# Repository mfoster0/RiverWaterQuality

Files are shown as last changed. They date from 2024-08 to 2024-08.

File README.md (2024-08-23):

# ♒Detecting River Water Quality 

<p align='center'>
  Final deployment in the River Lea
</p>
<br/>

## Contents
- [Overview](#overview) 
- [Features](#features) 
- [Hardware Components](#hardware-components) 
- [Set-up](#set-up) 
- [Usage](#usage)
- [Thanks](#Thanks) 
- [License](#license) 
- [Contact](#contact)

## Overview
<p align='center'>
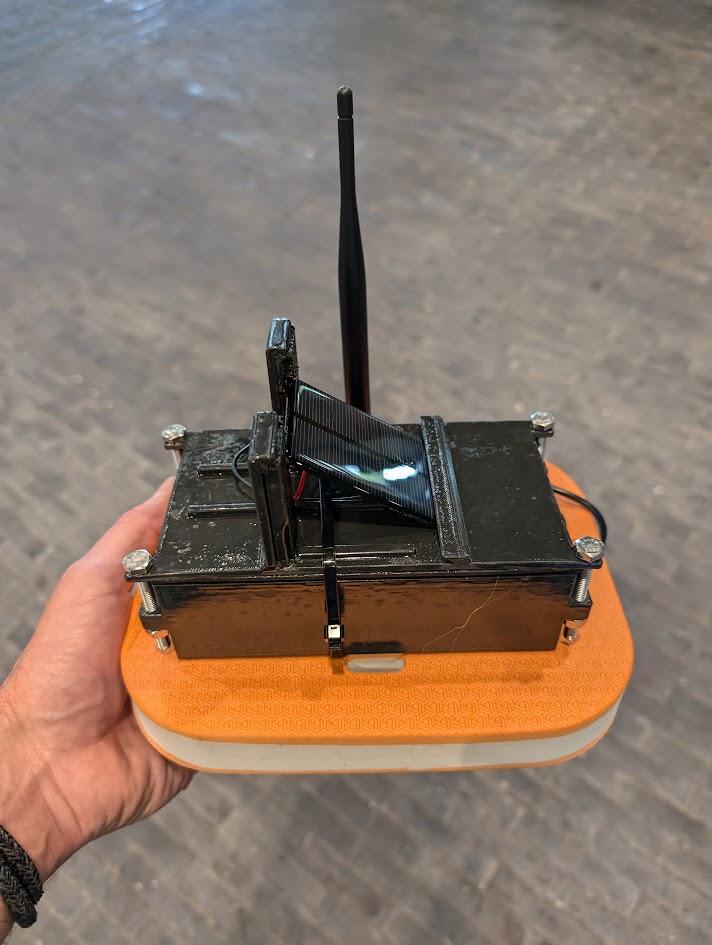
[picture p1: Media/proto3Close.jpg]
Prototype #3 before deployment
  
 </p>
This project created an IoT device that monitors river water quality in real-time. It detects temperature, electrical conductivity (EC) and the colour properties of water. It is an in-situ autonomous device that harvests solar energy and stores it in recycled vape batteries. The MCU is an Arduino MKR 1310 which sends the data over LoRa. The aim is to allow a user to remotely understand the changing water conditions to identify potential pollution events.
This project formed part of UCL Connected Environments MSc which concluded with an exhibition. This git also includes the exhibit details.
<br/>

<p align='center'>
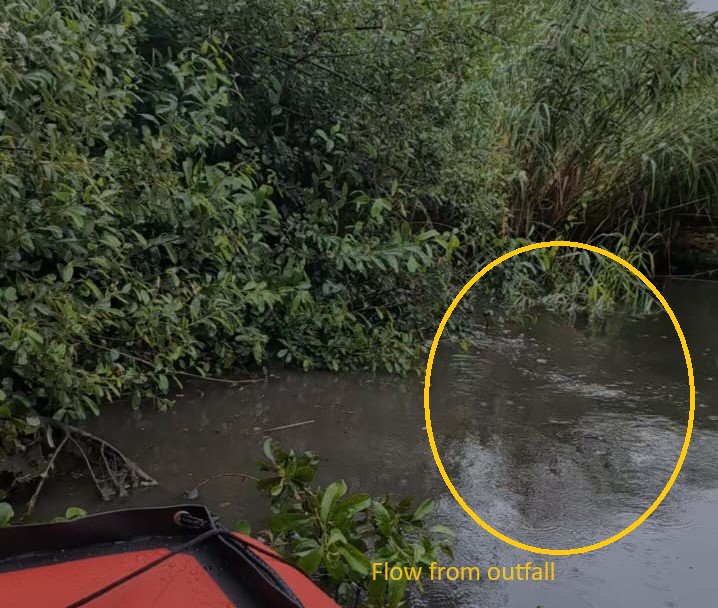
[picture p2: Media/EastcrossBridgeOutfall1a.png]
Location of deployment
  
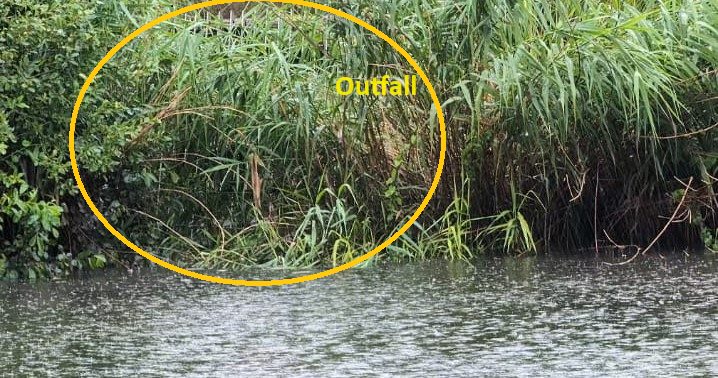
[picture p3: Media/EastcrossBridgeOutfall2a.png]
Deployment site
  
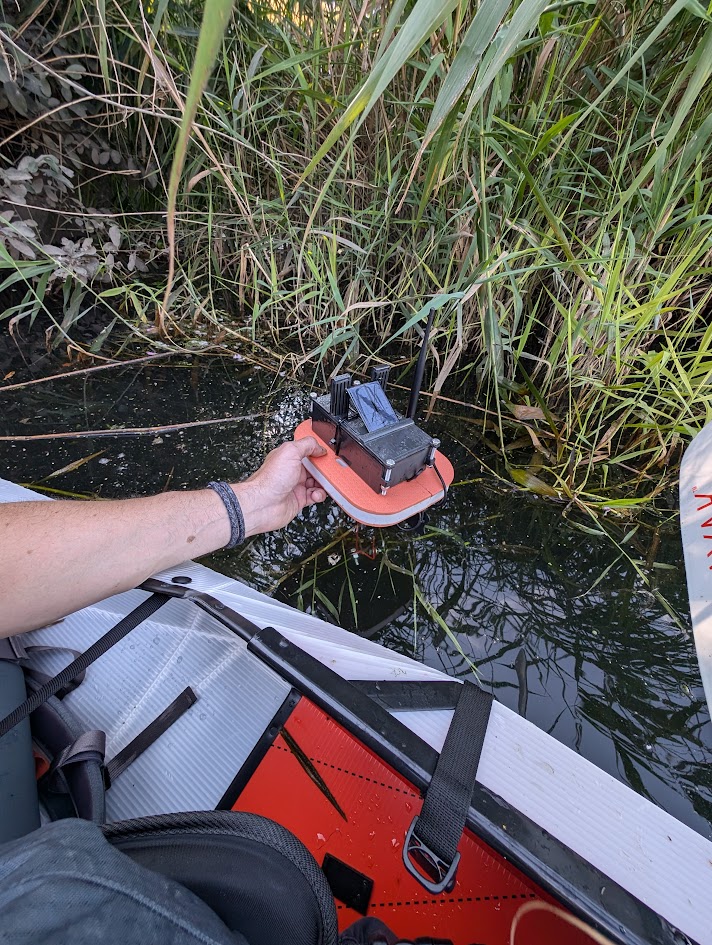
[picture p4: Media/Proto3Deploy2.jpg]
Prototype #3 being deployed
  
 
 </p>
 
## Features
- A custom 4-pole, graphite EC sensor
- Use of a TCS34725 with in external LED through optical fibre
- A DS18B20 temperature sensor
- LoRaWAN data transfer using Arduino MKR 1310
- Powered by a solar cell and upcycled vape batteries!

## Hardware Components 
- **Temperature Sensor** DS18B20
- **TCS34725 Colour Sensor**: [Learn more](https://www.waveshare.com/wiki/TCS34725_Color_Sensor) 
- **Custom Electrical Conductivity Sensor** inspired by the excellent Cave Pearl Project (https://thecavepearlproject.org/2017/08/12/measuring-electrical-conductivity-with-an-arduino-part1-overview/)
- **Arduino MKR1310 MCU** 
- **Solar Panel and Recycled Vape Batteries**

## Set-up
### Enclosure
The enclosure for this device was 3D printed with PLA and coated in an eco-friendly epoxy to waterproof it (tip: mixed results with this approach so thoroughly test how waterproof your final enclosure is). The files are in the *FusionFiles* directory. The float designs are included BUT the prototype deployed using these sank. The last version was deployed using a child’s kickboard as its float, which worked very well.

<p align='center'>
 The issues causes by not being waterproof can be seen below!

</p>
<p align='center'>
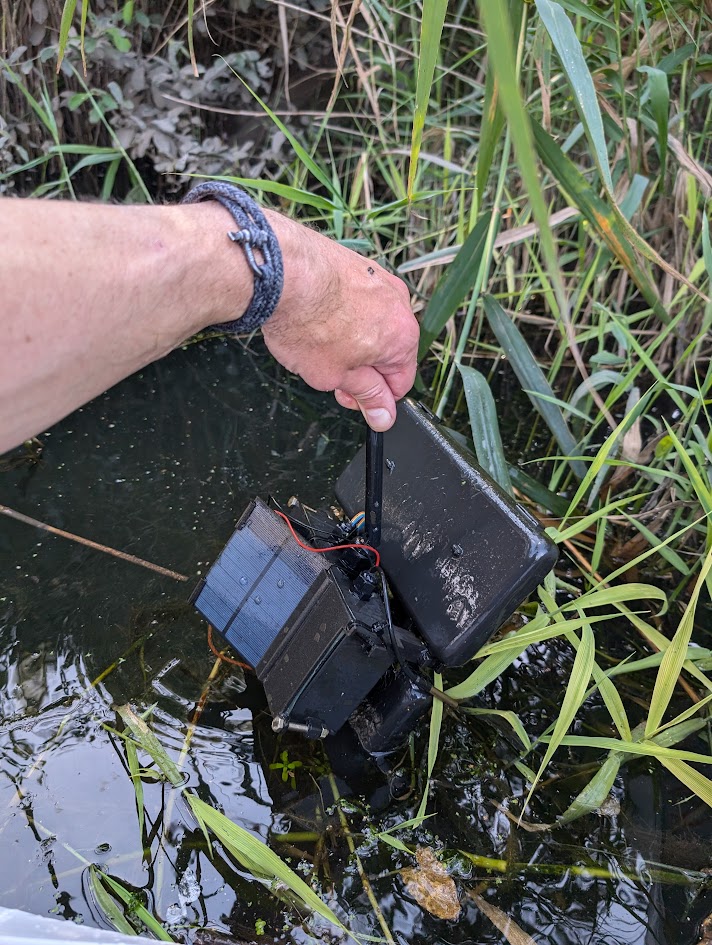
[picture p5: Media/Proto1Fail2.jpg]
A sunken prototype #1 being retrived
  
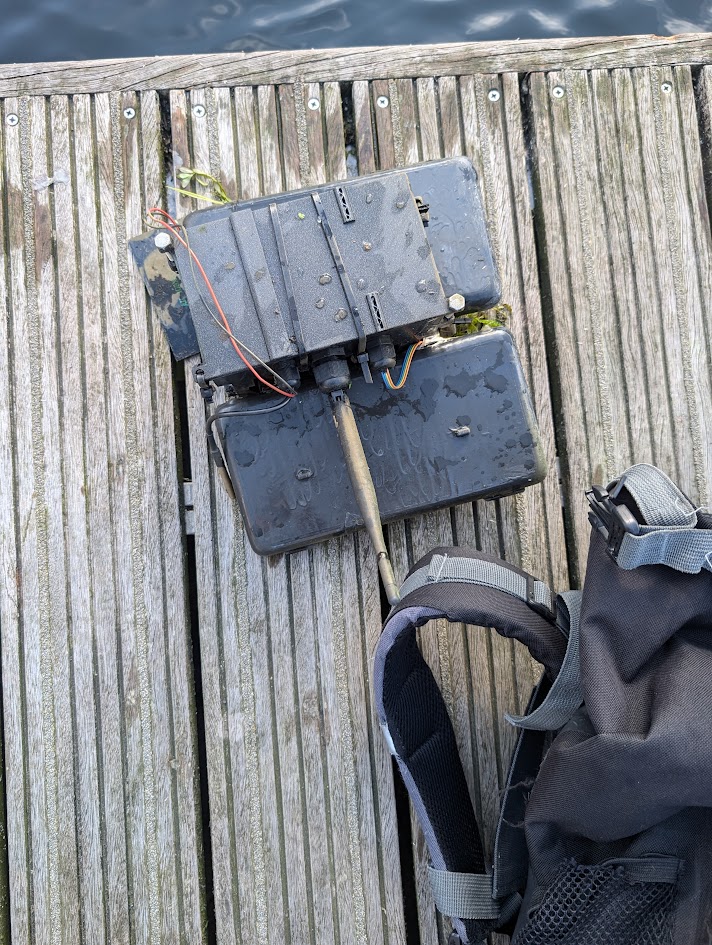
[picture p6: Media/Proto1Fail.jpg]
Prototype #1 after retrieval
  
 </p>
 
### Sensors
#### Electrical Conductivity (EC)
The EC sensor uses a 4-pole design to reduce electrolysis and increase the accuracy of the sensor. Graphite was used for electrodes for its high conductivity and resistance to electrolysis. The prototypes used 2mm 8B graphite to maximise the conductivity of the graphite but, due to its softness, this is difficult to work with. A conductive glue was used to attach the electrode to the wire.
The current oscillates from the two outer poles, with the two inner poles measuring the voltage. A third voltage measurement is taken across one of the resistors connected to the outer poles. 
<p align='center'>
 Below are images of the electrode holder 3D model and the graphite electrodes attached using conductive glue.
</p>
<p align='center'>
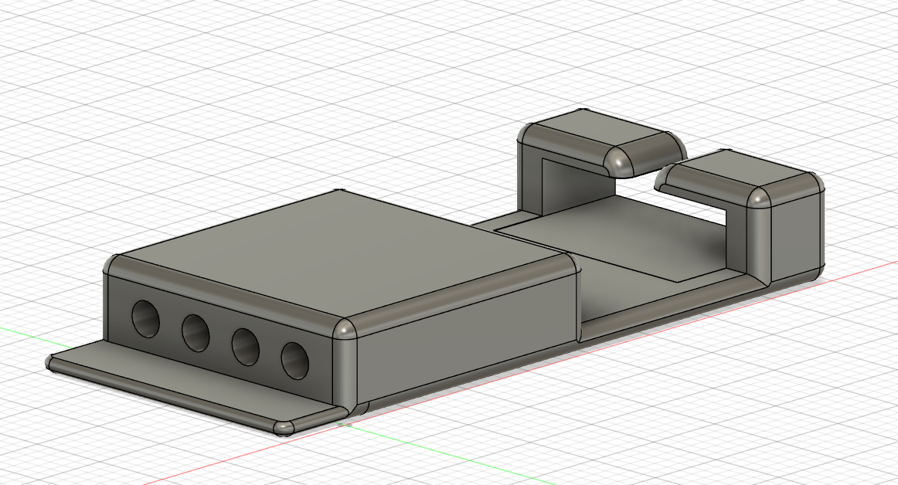
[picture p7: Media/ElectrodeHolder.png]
3D model of the electrode holder
   
 
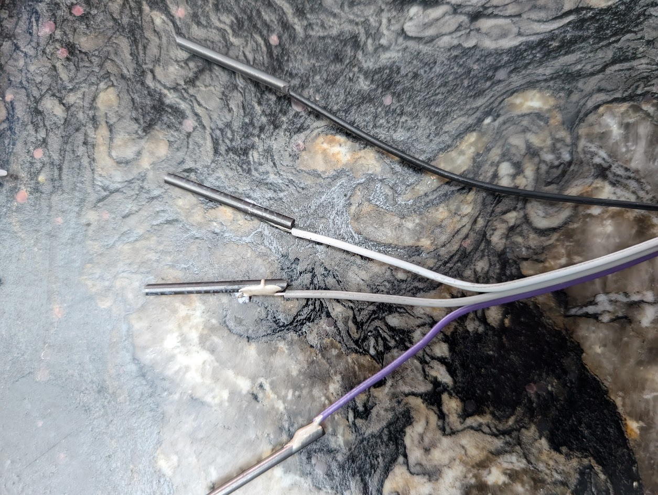
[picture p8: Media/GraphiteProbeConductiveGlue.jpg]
Photo of the 4 wires attached to the graphite electrodes with conductive glue
   
 </p>

#### TCS34725
To detect the colour of the water, light was emitted from a white LED, transmitted through the water and detected by the TCS34725. The sensor is keep away from the water by using optical fibre to transfer the light into and out of the water. An early version made use of the sensor’s onboard LED using backscattered light for colour detection but the results were poor which led to the latest design where light source is directed at the sensor.
<p align='center'>
 Below are the TCS34725 sensor and 3D print of optical fibre frame with its water chamber visible in the center
</p>
<p align='center'>
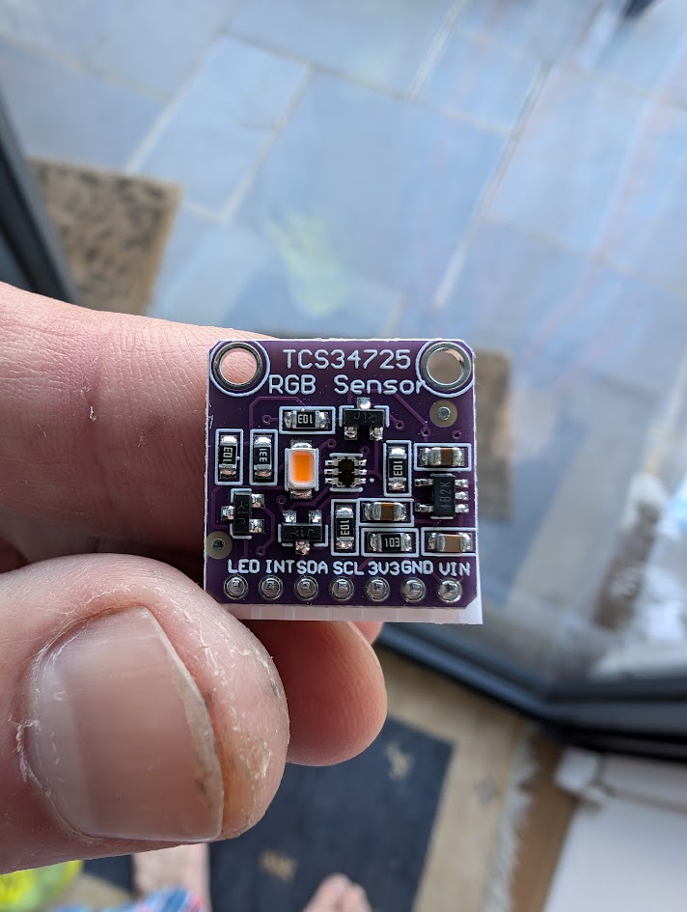
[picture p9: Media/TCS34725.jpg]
Photo of the TCS34725
   
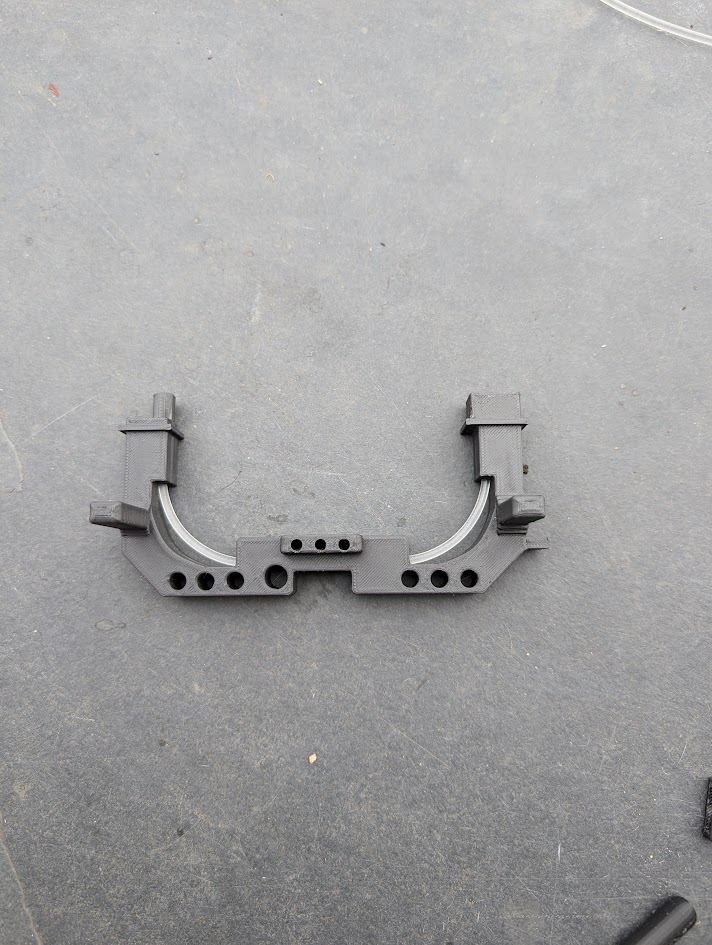
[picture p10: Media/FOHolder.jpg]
Photo of the Optical Fibre holder
   
 </p>

#### DS18B20
The temperature sensor had no modifications and has the standard 4.7k ohm resistor setup. https://www.researchgate.net/figure/Design-of-Ds1820-Temperature-Sensor_fig3_260944398
#### Circuit
Below are the circuit diagrams. Through testing 510 ohm resistors were found to give the most sensitive results for pure water to sea water salinity levels.

A custom PCB was used for the final build. Files are in the *FusionFiles/PCB* folder. The resistor component had a short in the protoype. That is corrected in these files. The schematic is correct but make sure to double check the PCB if this to be used.

<p align='center'>
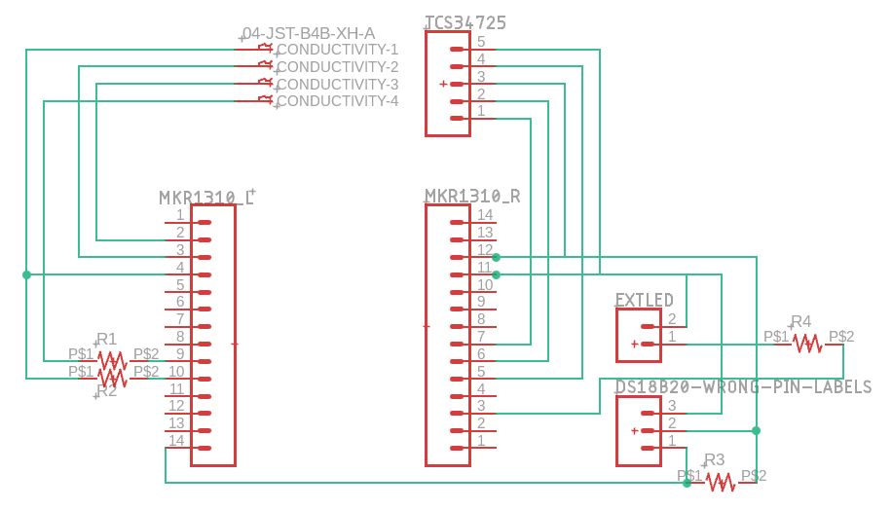
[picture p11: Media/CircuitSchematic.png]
Schematic for the circuit
  
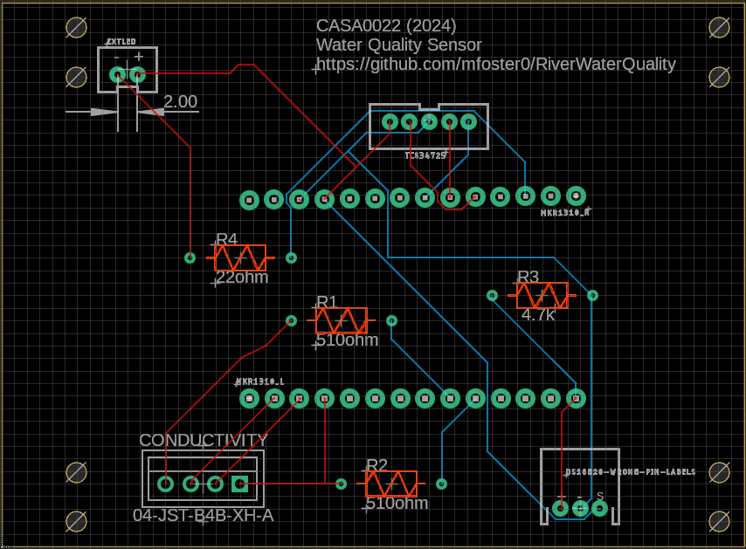
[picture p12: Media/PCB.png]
PCB Design
  
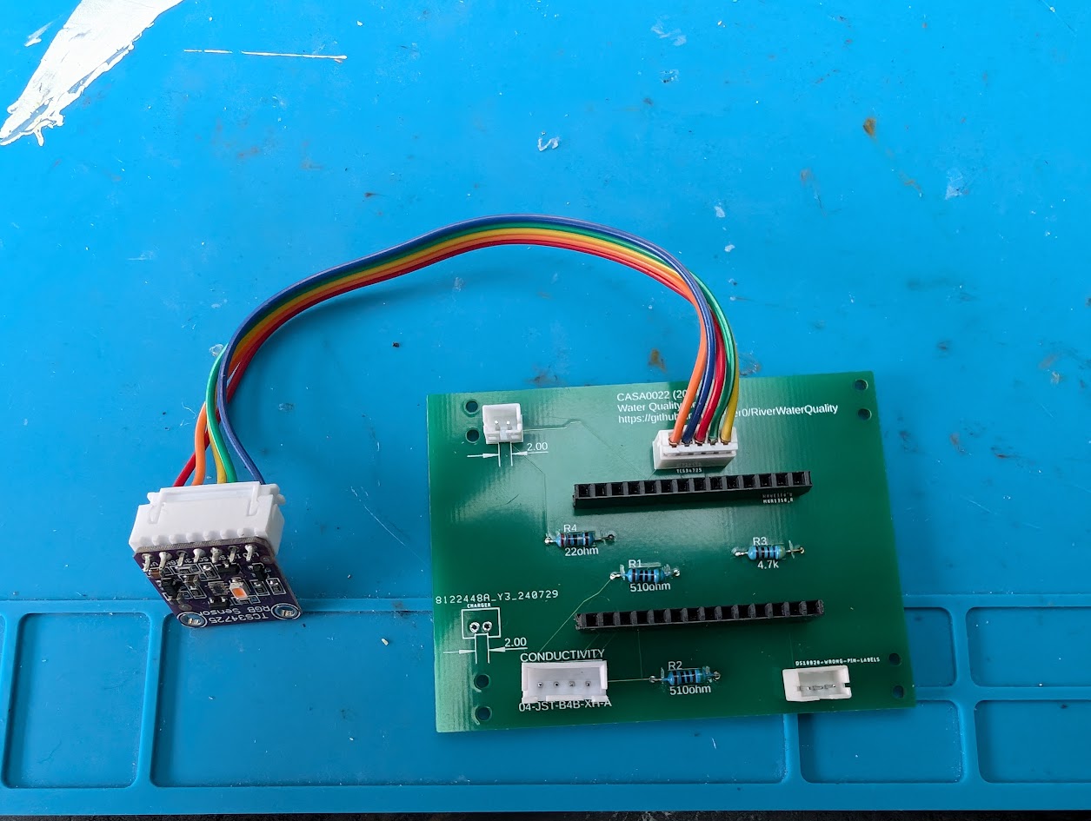
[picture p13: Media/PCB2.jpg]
Image of the actual PCB
  
 </p>

### Code
*Prod_RiverWaterQuality* holds the Arduino code for the final version. Multiple boards and sensors were tested before arriving at this version. Some of the code for those is stored in the *InitalScripts* directory.  

The read of the voltages values are taken in the loop with the pin outputs alternating between HIGH and LOW to get the oscillating current.
```c++
//function to get conductivity values
//to the code takes multiple readings
//the highest and lowest values are dropped to help reduce the opportunity for erroneous values to be included
//the central values are then averaged 
void processConductivity(){
  // Generate oscillating current and read voltages
  std::vector<int> readings1;
  std::vector<int> readings2;
  std::vector<int> resistorReadings;
  
  unsigned long startTime = millis();
  int sampleCount = 0;

  //loop for specified time taking multiple readings
  while (millis() - startTime < SAMPLE_DELAY) {
    digitalWrite(OUTER_ELECTRODE1, HIGH);
    digitalWrite(OUTER_ELECTRODE2, LOW);
    delayMicroseconds(500000 / OSCILLATION_FREQUENCY);
    
    readings1.push_back(analogRead(INNER_ELECTRODE1));
    readings2.push_back(analogRead(INNER_ELECTRODE2));
    resistorReadings.push_back(analogRead(RESISTOR_READ));
    sampleCount++;
    
    digitalWrite(OUTER_ELECTRODE1, LOW);
    digitalWrite(OUTER_ELECTRODE2, HIGH);
    delayMicroseconds(500000 / OSCILLATION_FREQUENCY);
    
    readings1.push_back(analogRead(INNER_ELECTRODE1));
    readings2.push_back(analogRead(INNER_ELECTRODE2));
    resistorReadings.push_back(analogRead(RESISTOR_READ));
    sampleCount++;
  }
  
  //process the arrays, dropping highest and lowest values before averaging
  float avgVoltage1 = trimAndAverageReadings(readings1, sampleCount);
  float avgVoltage2 = trimAndAverageReadings(readings2, sampleCount);
  float avgResistorVoltage = trimAndAverageReadings(resistorReadings, sampleCount);
  
  //read temperature
  sensors.requestTemperatures(); // get temperature
  float temperature = sensors.getTempCByIndex(0); // Get temperature in Celsius
  Temperature = (uint16_t)(temperature * 100.0);
  Serial.print("temperature: ");
  Serial.println(temperature,3);
  Serial.println(Temperature);

  //convert to voltages
  float voltage1 = (avgVoltage1 / UPPER_BOUND) * BOARD_VOLTAGE;
  float voltage2 = (avgVoltage2 / UPPER_BOUND) * BOARD_VOLTAGE;
  float resistorVoltage = (avgResistorVoltage / UPPER_BOUND) * BOARD_VOLTAGE;

  // Calc voltage drop in solution
  float solutionVoltage = voltage2 - voltage1;

  // Calc resistance of solution
  float resistance = resistorVoltage / (solutionVoltage / RESISTOR_VALUE); 

  // Calc raw conductivity - any temperature compensation to be done off device
  float rawConductivity = 1.0 / resistance; 

  Conductivity = (uint16_t)(rawConductivity * 100);
  Serial.println(Conductivity);

```
The reads do get anomalies. To counter this many reads are taken with just the central values being used and the highest and lowest values dropped.  
```c++
//drop highest and lowest n% of values to reduce noise
float trimAndAverageReadings(std::vector<int>& readings, int numReadings) {
    if (readings.empty() || numReadings < 3) {
        return 0.0f;  // return 0 if the list is empty or numReadings is too small
    }

    //sort the vector
    std::sort(readings.begin(), readings.end());

    // calc number of elements to trim
    int trimCount = std::round(numReadings * 0.2);  // 20% from top and bottom
    
    // don't trim more than half the values
    trimCount = std::min(trimCount, ((int)readings.size() / 2) - 1);

    // sum up
    float sum = 0;
    for (int i = trimCount; i < readings.size() - trimCount; ++i) {
        sum += readings[i];
    }

    // retrun average
    int remainingElements = readings.size() - (2 * trimCount); //2x - 1 at each end
    return sum / remainingElements;
}
```
The device sleeps for 10 minutes between reads (*LowPower.deepSleep(600000);*). This ensures that it conserves power and stays well within The Things Network fair use conditions. When the device wakes it reads the current sensor values and sends them using LoRa.
```c++
//from setup
…
  //startup LoRa modem instance set regional band 
  if (!modem.begin(EU868)) {
    Serial.println("Failed to start module");
  }

  Serial.print("Your device EUI is: ");
  Serial.println(modem.deviceEUI());

  int connected = modem.joinOTAA(appEui, appKey);
  if (!connected) {
    Serial.println("Unable to connect");
  }
…

//send data over LoRaWAN
void sendLora(){
    // Split readings (16 bits) into 2 bytes of 8
  int payloadLen = 10;
  Serial.println(payloadLen);
  
  byte payload[payloadLen];
  payload[0] = highByte(Temperature);
  payload[1] = lowByte(Temperature);
  payload[2] = highByte(Conductivity);
  payload[3] = lowByte(Conductivity);
  
  payload[4] = highByte(Red);
  payload[5] = lowByte(Red);
  payload[6] = highByte(Green);
  payload[7] = lowByte(Green);
  payload[8] = highByte(Blue);
  payload[9] = lowByte(Blue);

  modem.beginPacket();
  modem.write(payload, sizeof(payload));
  int err = modem.endPacket(true);
  if (err > 0) {
    Serial.println("Message sent correctly");
  } else {
    Serial.println("Error sending message");
  }
}

```

## Thanks
 - Dr Izzy Bishop (UCL) for input and help deploying the devices
 - Lewis Elmes (Environment Agency) for approving the deployments

## License
MIT License

Copyright (c) 2024 mfoster0

Permission is hereby granted, free of charge, to any person obtaining a copy
of this software and associated documentation files (the "Software"), to deal
in the Software without restriction, including without limitation the rights
to use, copy, modify, merge, publish, distribute, sublicense, and/or sell
copies of the Software, and to permit persons to whom the Software is
furnished to do so, subject to the following conditions:

The above copyright notice and this permission notice shall be included in all
copies or substantial portions of the Software.

THE SOFTWARE IS PROVIDED "AS IS", WITHOUT WARRANTY OF ANY KIND, EXPRESS OR
IMPLIED, INCLUDING BUT NOT LIMITED TO THE WARRANTIES OF MERCHANTABILITY,
FITNESS FOR A PARTICULAR PURPOSE AND NONINFRINGEMENT. IN NO EVENT SHALL THE
AUTHORS OR COPYRIGHT HOLDERS BE LIABLE FOR ANY CLAIM, DAMAGES OR OTHER
LIABILITY, WHETHER IN AN ACTION OF CONTRACT, TORT OR OTHERWISE, ARISING FROM,
OUT OF OR IN CONNECTION WITH THE SOFTWARE OR THE USE OR OTHER DEALINGS IN THE
SOFTWARE.

## Contact
Please let me know if you find errors in here or if you taking the project further.
ucfnamm@ucl.ac.uk

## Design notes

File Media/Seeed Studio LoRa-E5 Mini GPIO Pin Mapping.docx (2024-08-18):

Seeed Studio LoRa-E5 Mini GPIO Pin Mapping

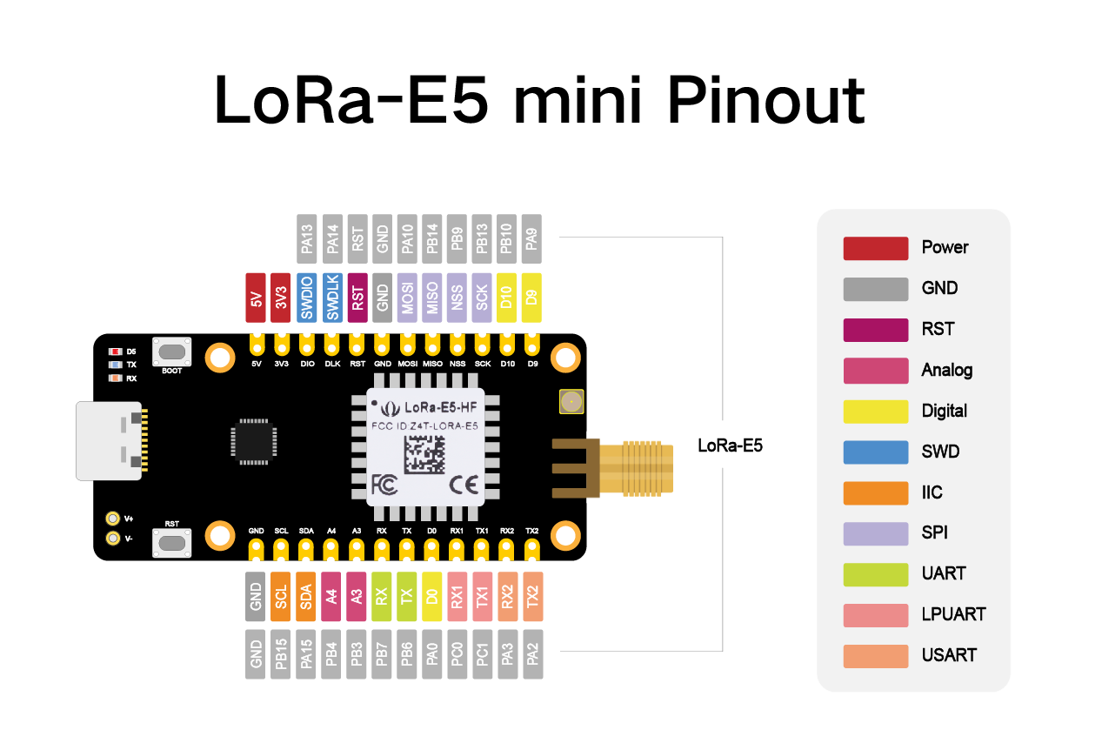
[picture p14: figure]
pir

Pin | Pin # | HAL GPIO Pin | | Pin | Pin # | HAL GPIO Pin | | Pin | Pin # | HAL GPIO Pin
PA0 | 18 | GPIO_PIN_0 | | PB1 | 33 | GPIO_PIN_1 | | PC2 | 43 | GPIO_PIN_2
PA1 | 19 | GPIO_PIN_1 | | PB2 | 34 | GPIO_PIN_2 | | PC3 | 44 | GPIO_PIN_3
PA2 | 20 | GPIO_PIN_2 | | PB3 | 3 | GPIO_PIN_3 | | PC4 | 45 | GPIO_PIN_4
PA3 | 21 | GPIO_PIN_3 | | PB4 | 4 | GPIO_PIN_4 | | PC5 | 46 | GPIO_PIN_5
PA4 | 22 | GPIO_PIN_4 | | PB5 | 5 | GPIO_PIN_5 | | PC6 | 47 | GPIO_PIN_6
PA5 | 23 | GPIO_PIN_5 | | PB6 | 6 | GPIO_PIN_6 | | PC7 | 48 | GPIO_PIN_7
PA6 | 24 | GPIO_PIN_6 | | PB7 | 7 | GPIO_PIN_7 | | PC8 | 49 | GPIO_PIN_8
PA7 | 25 | GPIO_PIN_7 | | PB8 | 8 | GPIO_PIN_8 | | PC9 | 50 | GPIO_PIN_9
PA8 | 26 | GPIO_PIN_8 | | PB9 | 9 | GPIO_PIN_9 | | PC10 | 51 | GPIO_PIN_10
PA9 | 11 | GPIO_PIN_9 | | PB10 | 35 | GPIO_PIN_10 | | PC11 | 52 | GPIO_PIN_11
PA10 | 12 | GPIO_PIN_10 | | PB11 | 36 | GPIO_PIN_11 | | PC12 | 53 | GPIO_PIN_12
PA11 | 13 | GPIO_PIN_11 | | PB12 | 37 | GPIO_PIN_12 | | PC13 | 2 | GPIO_PIN_13
PA12 | 14 | GPIO_PIN_12 | | PB13 | 38 | GPIO_PIN_13 | | PC14 | 16 | GPIO_PIN_14
PA13 | 29 | GPIO_PIN_13 | | PB14 | 39 | GPIO_PIN_14 | | PC15 | 17 | GPIO_PIN_15
PA14 | 30 | GPIO_PIN_14 | | PB15 | 40 | GPIO_PIN_15 | | PD0 | 54 | GPIO_PIN_0
PA15 | 31 | GPIO_PIN_15 | | PC0 | 41 | GPIO_PIN_0 | | PD1 | 55 | GPIO_PIN_1
PB0 | 32 | GPIO_PIN_0 | | PC1 | 42 | GPIO_PIN_1

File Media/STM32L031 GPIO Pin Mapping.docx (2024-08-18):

# STM32L031 GPIO Pin Mapping

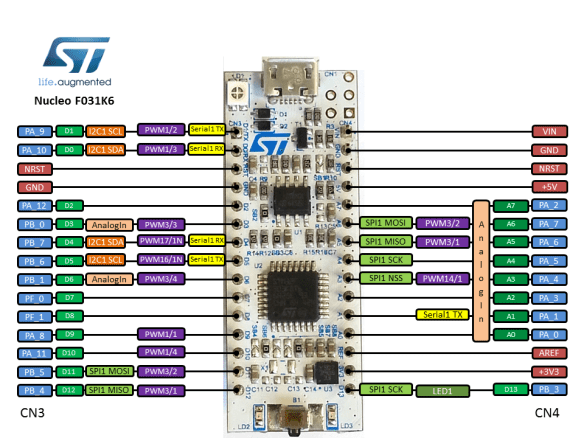
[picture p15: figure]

Pin | Pin # | HAL GPIO Pin Definition | | Pin | Pin # | HAL GPIO Pin Definition | | Pin | Pin # | HAL GPIO Pin Definition
PA0 | 1 | GPIO_PIN_0 | | PA12 | 19 | GPIO_PIN_12 | | PB8 | 32 | GPIO_PIN_8
PA1 | 2 | GPIO_PIN_1 | | PA13 | 21 | GPIO_PIN_13 | | PB9 | 33 | GPIO_PIN_9
PA2 | 3 | GPIO_PIN_2 | | PA14 | 22 | GPIO_PIN_14 | | PB10 | 34 | GPIO_PIN_10
PA3 | 4 | GPIO_PIN_3 | | PA15 | 23 | GPIO_PIN_15 | | PB11 | 35 | GPIO_PIN_11
PA4 | 5 | GPIO_PIN_4 | | PB0 | 24 | GPIO_PIN_0 | | PB12 | 36 | GPIO_PIN_12
PA5 | 6 | GPIO_PIN_5 | | PB1 | 25 | GPIO_PIN_1 | | PB13 | 37 | GPIO_PIN_13
PA6 | 7 | GPIO_PIN_6 | | PB2 | 26 | GPIO_PIN_2 | | PB14 | 38 | GPIO_PIN_14
PA7 | 8 | GPIO_PIN_7 | | PB3 | 27 | GPIO_PIN_3 | | PB15 | 39 | GPIO_PIN_15
PA8 | 15 | GPIO_PIN_8 | | PB4 | 28 | GPIO_PIN_4 | | PC13 | 40 | GPIO_PIN_13
PA9 | 16 | GPIO_PIN_9 | | PB5 | 29 | GPIO_PIN_5 | | PC14 | 41 | GPIO_PIN_14
PA10 | 17 | GPIO_PIN_10 | | PB6 | 30 | GPIO_PIN_6 | | PC15 | 42 | GPIO_PIN_15
PA11 | 18 | GPIO_PIN_11 | | PB7 | 31 | GPIO_PIN_7

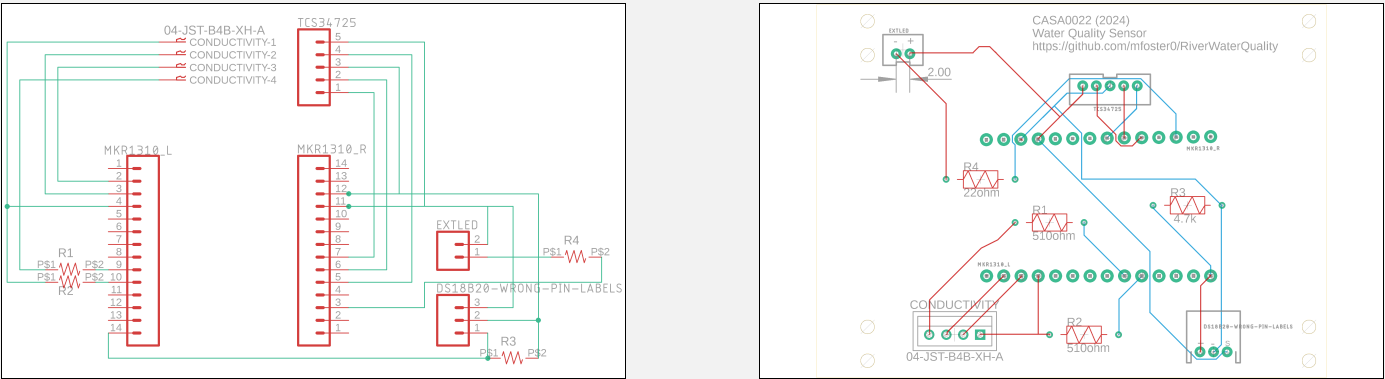
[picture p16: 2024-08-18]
Media/CircuitSchematicAndPCB.png

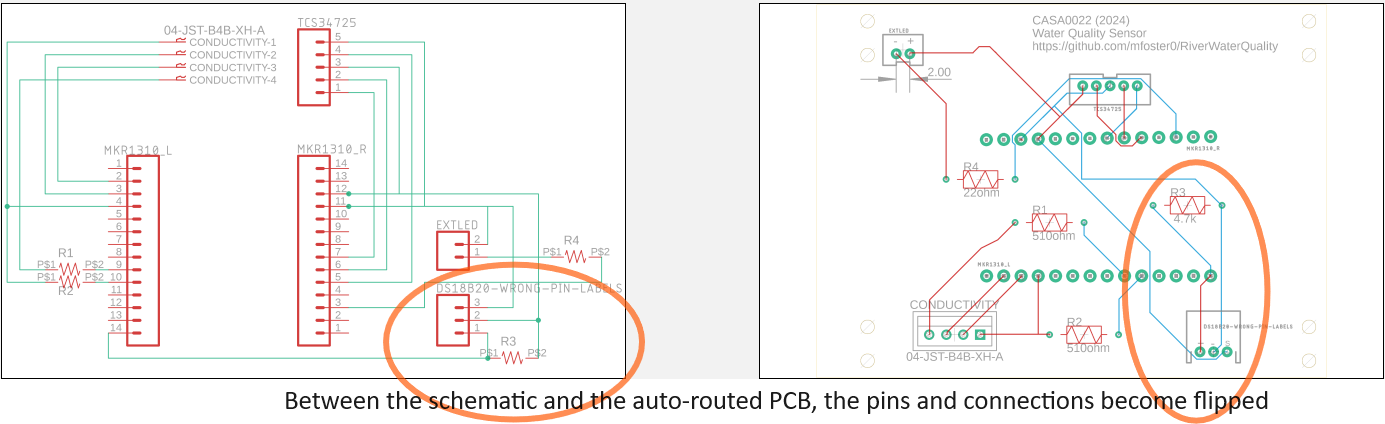
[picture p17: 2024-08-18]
Media/CircuitSchematicAndPCBText.png

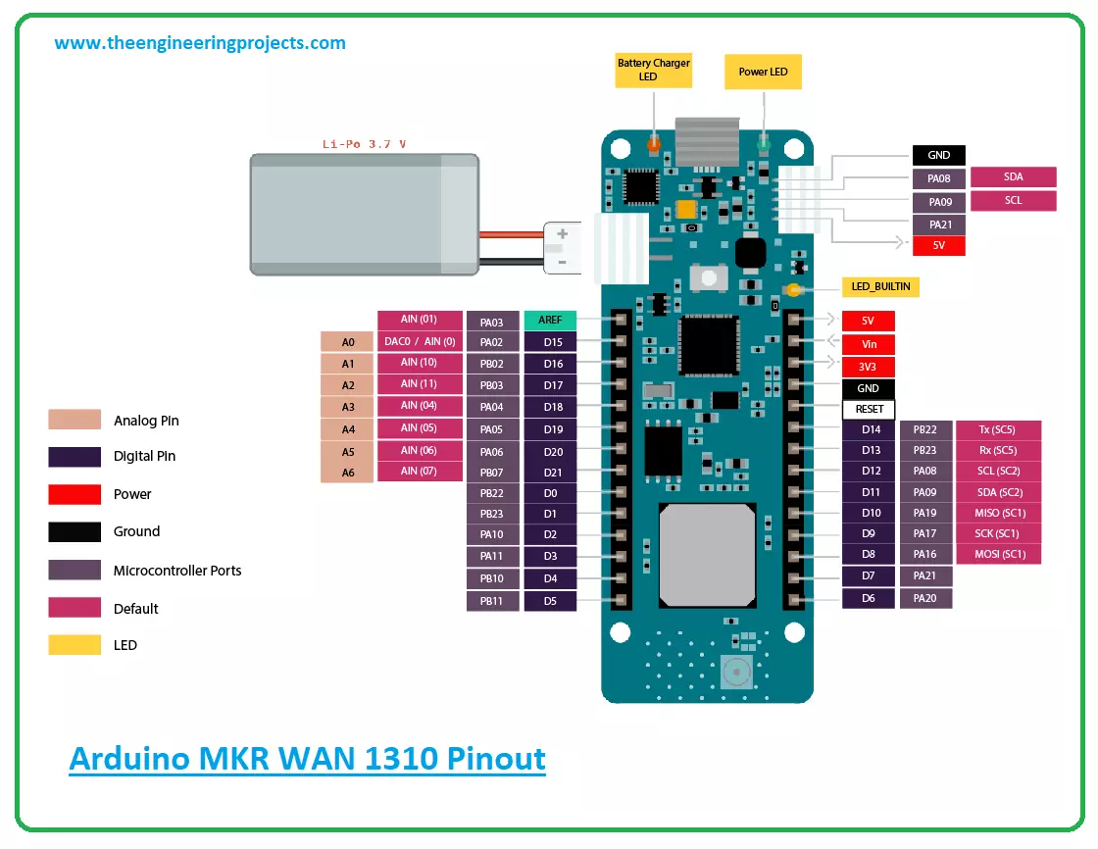
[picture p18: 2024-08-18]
Media/Arduino-MKR-WAN-1310-Pinout.webp

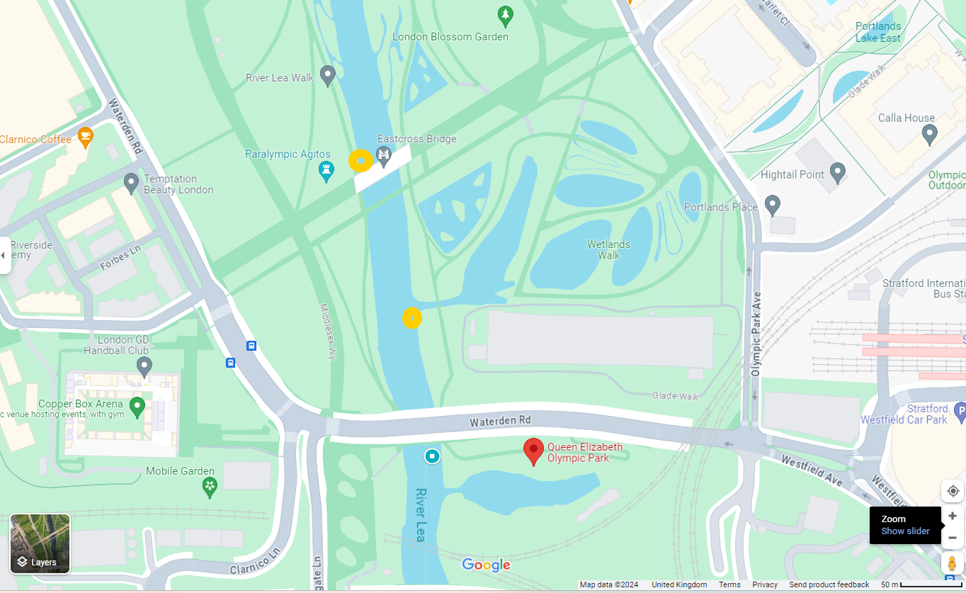
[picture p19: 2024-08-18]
Media/DeploymentSitesZoomOut.png

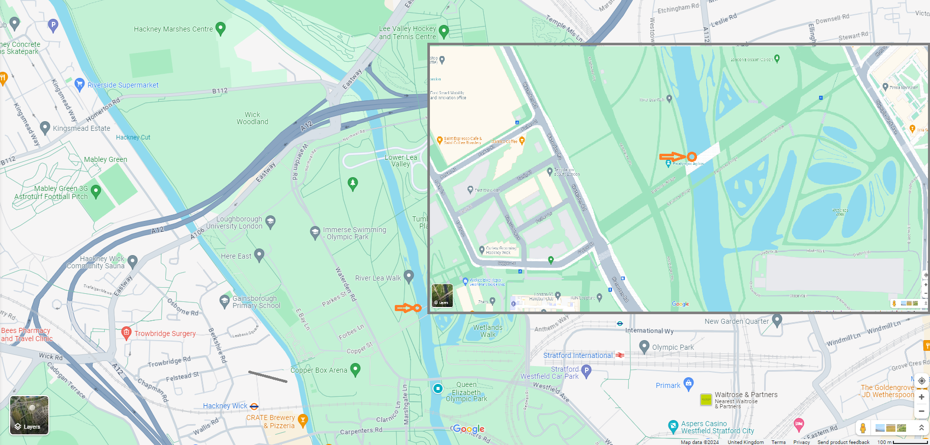
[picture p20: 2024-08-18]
Media/DeploymentLoc.png

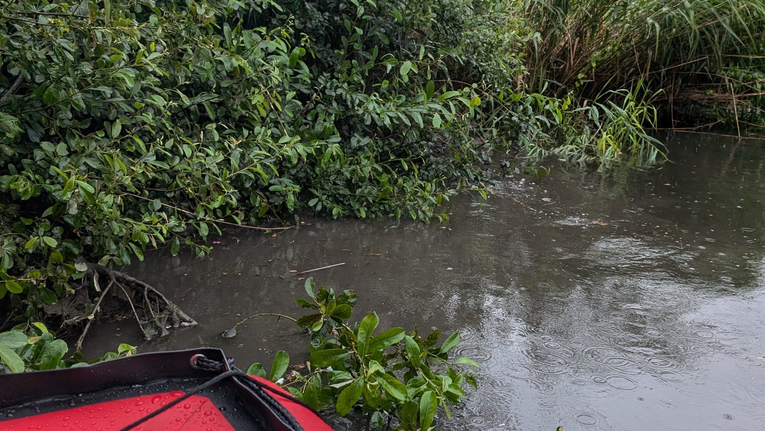
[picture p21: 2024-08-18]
Media/OutfallDump2.html.jpg

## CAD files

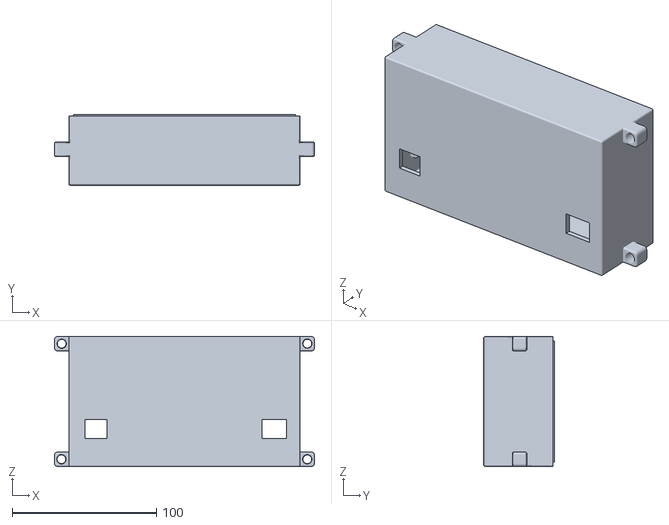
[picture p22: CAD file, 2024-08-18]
FusionFiles/Device/MainEnclosureBox v8.stl
180.0 x 49.0 x 90.0

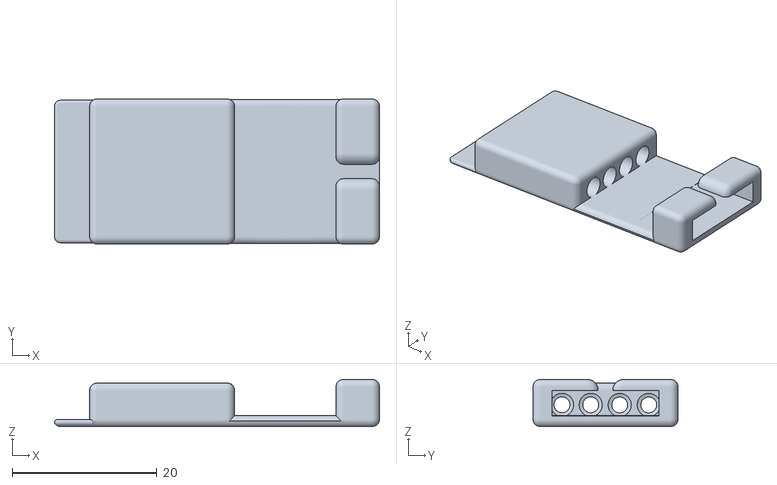
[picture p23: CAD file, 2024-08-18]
FusionFiles/Device/ElectrodeHolder v2.stl
44.8 x 20.0 x 6.50

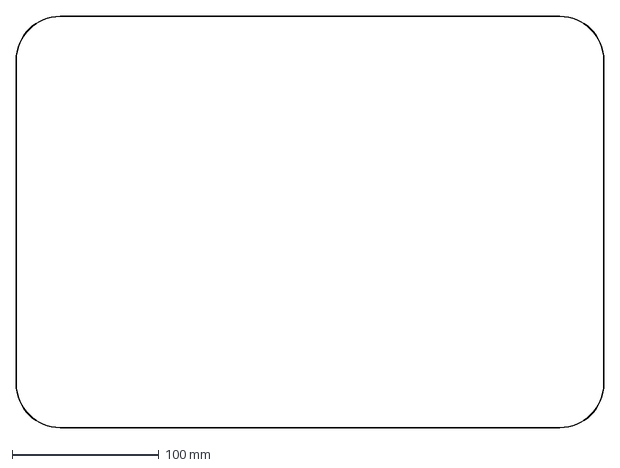
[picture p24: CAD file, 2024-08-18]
FusionFiles/Exhibit/ExhibitionBase v1.dxf
400.0 x 280.0 mm

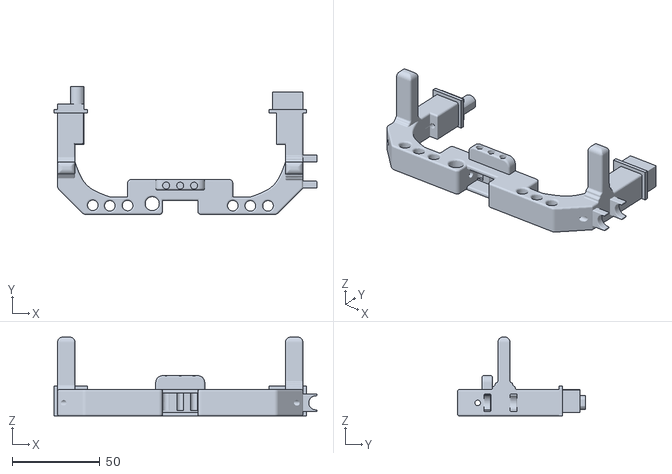
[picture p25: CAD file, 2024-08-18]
FusionFiles/Device/OpticalFibreHolderV3 v7.stl
150.0 x 73.0 x 45.0

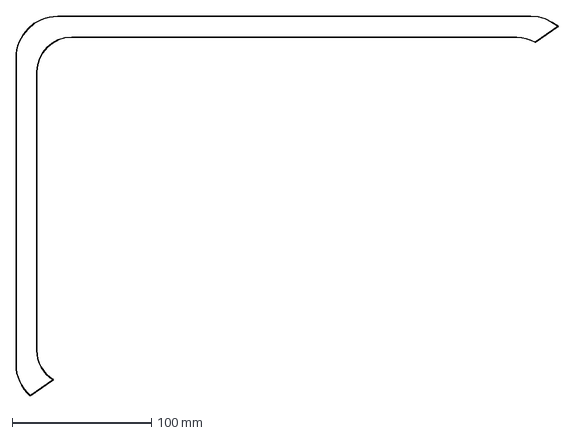
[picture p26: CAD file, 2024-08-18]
FusionFiles/Exhibit/ExhibitionSide v2.dxf
389.6 x 272.7 mm

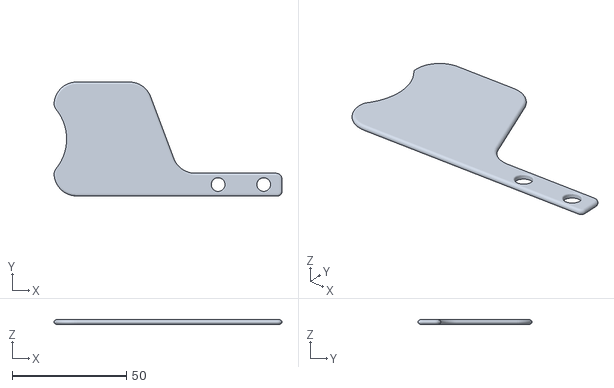
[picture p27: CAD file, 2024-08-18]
FusionFiles/Device/Fin v2.stl
100.0 x 50.0 x 2.00

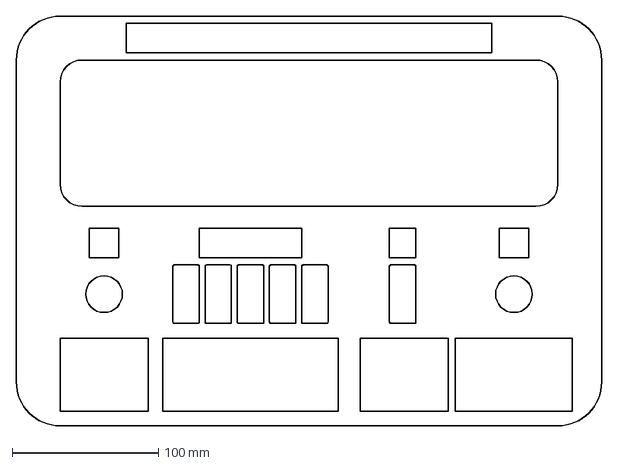
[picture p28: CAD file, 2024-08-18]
FusionFiles/Exhibit/ExhibitionTop v2.dxf
400.0 x 280.0 mm

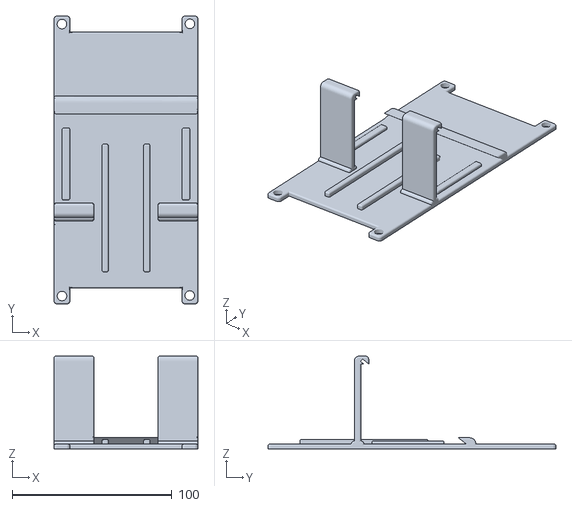
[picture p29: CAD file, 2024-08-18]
FusionFiles/Device/Lid v3.stl
90.0 x 180.0 x 58.0

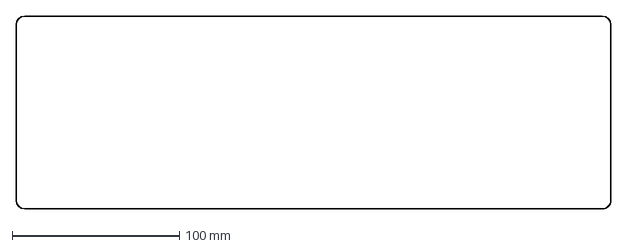
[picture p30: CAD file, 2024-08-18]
FusionFiles/Exhibit/AcrylicLEDWindow v2.dxf
355.0 x 115.0 mm

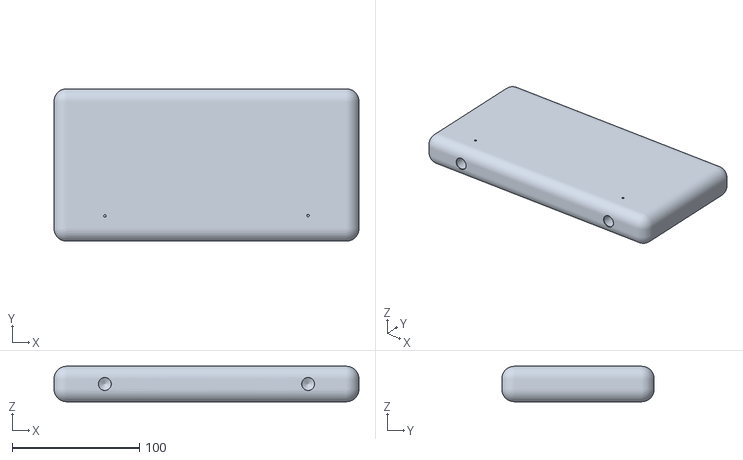
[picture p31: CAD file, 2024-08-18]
FusionFiles/Device/FloatIn v2.stl
240.0 x 120.0 x 28.0

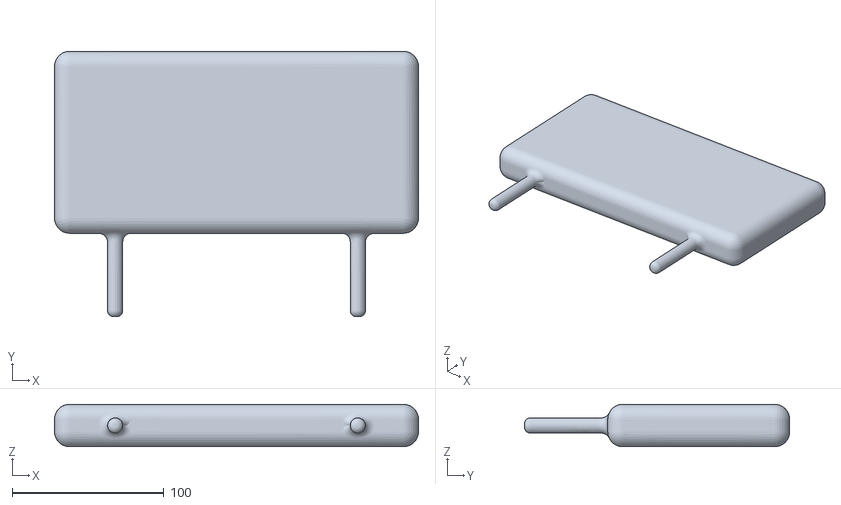
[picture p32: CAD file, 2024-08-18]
FusionFiles/Device/FloatOut v2.stl
240.0 x 175.0 x 28.0

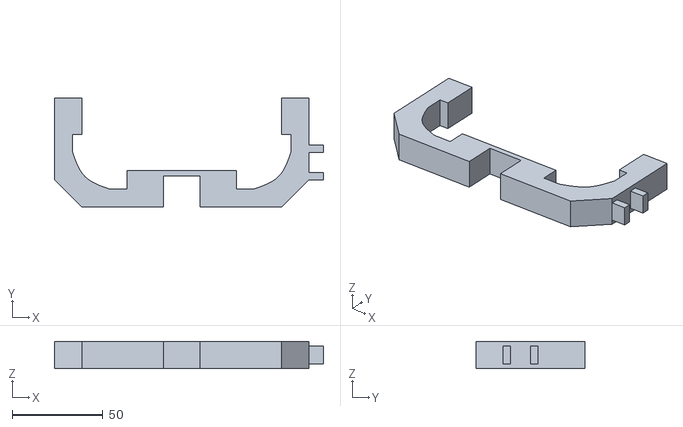
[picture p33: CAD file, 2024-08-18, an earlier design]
FusionFiles/Device/PreviousVersions/MainEnclosureHolder v1.stl
148.0 x 60.0 x 15.0

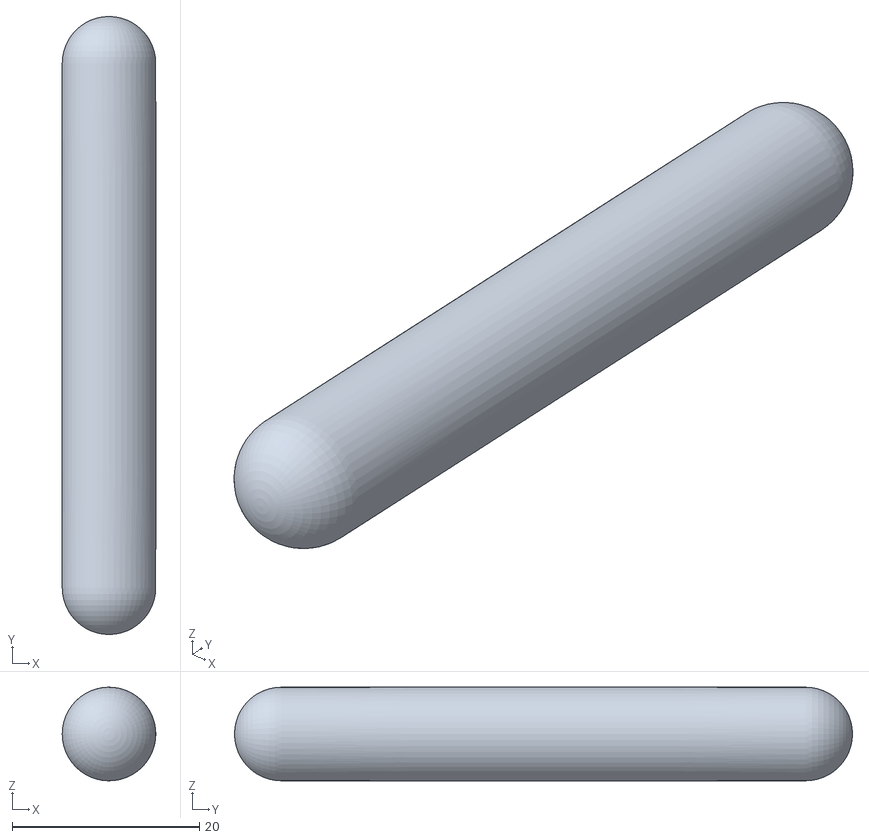
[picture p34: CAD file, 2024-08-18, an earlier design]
FusionFiles/Device/PreviousVersions/RodLong v1.stl
10.0 x 66.0 x 10.0

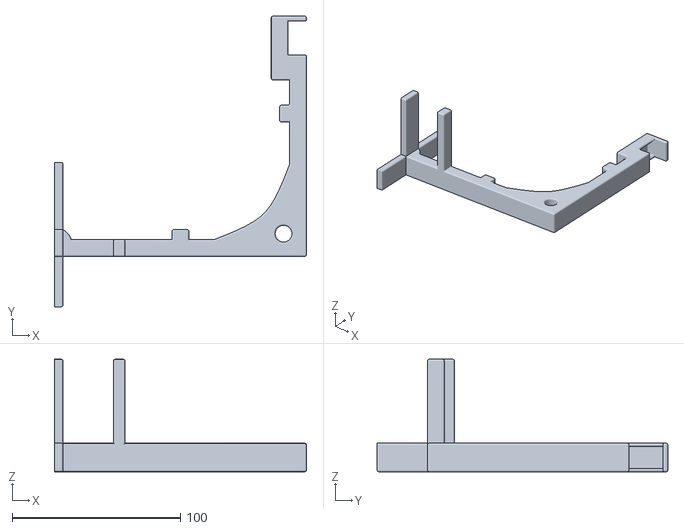
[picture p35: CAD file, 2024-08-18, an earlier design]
FusionFiles/Device/PreviousVersions/OpticalFibreHolderShortened v3.stl
150.0 x 173.0 x 67.0

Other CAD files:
FusionFiles/Device/PreviousVersions/OpticalFibreHolderShortenedNoFloatHolder v3.stl
FusionFiles/Device/PreviousVersions/StackableFloat v1.stl
FusionFiles/Device/PreviousVersions/FloatP2 v2.stl
FusionFiles/Device/PreviousVersions/Rudder v1.stl
FusionFiles/Device/ElectrodeHolder v2.f3d
FusionFiles/Device/Fin v2.f3d
FusionFiles/Device/FloatIn v2.f3d
FusionFiles/Device/FloatOut v2.f3d
FusionFiles/Device/Lid v3.f3d
FusionFiles/Device/MainEnclosureBox v8.f3d
FusionFiles/Device/MainEnclosureFibreHolder v4.f3d
FusionFiles/Device/OpticalFibreHolderV3 v7.f3d
FusionFiles/Device/PreviousVersions/FloatP1 v1.stl
FusionFiles/Device/PreviousVersions/OpticalFibreHolder v2.stl
FusionFiles/PCB/CircuitSchematic v20.f3z

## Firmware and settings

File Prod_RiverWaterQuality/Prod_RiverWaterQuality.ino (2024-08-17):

/////////////////////////////////////////////////////////////////////////////////////
/// This sketch is designed for the CE final project
/// It is intended for use with 3 sensors - DS18B20, TCS34725 and a home made 4 pole conductivity sensor
/// It intermittently performs reads on the sesnors and sends the data over LoRa. 
/// Conductivity and RGB readings are taken multiple times, topped and tailed to remove outliers, leaving the core readings which are averaged before sending
/// It is based on examples from Adafruit, Dallas, Arduino LoRa
/// The 4 pole design is based on the idea in //https://thecavepearlproject.org/2017/08/12/measuring-electrical-conductivity-with-an-arduino-part1-overview/
/// Coded by mfoster
/////////////////////////////////////////////////////////////////////////////////////

#include <Wire.h>
#include "Adafruit_TCS34725.h"
#include <vector>
#include <algorithm>
#include <cmath>
#include <DallasTemperature.h>
#include "ArduinoLowPower.h"
#include <MKRWAN.h>
#include "secrets.h" //get char *appKey and char *appEui

LoRaModem modem;


/* Adapted from example code for the Adafruit TCS34725 breakout library */

/* For Nano set up
   Connect SCL    to analog 5
   Connect SDA    to analog 4
   Connect VDD    to 3.3V DC
   Connect GROUND to common ground 
   TCS LED to D2/PIN 2
   */

 /* For MKR1310 set up
   Connect SCL    D12/SCL
   Connect SDA    D11/SDA
   Connect VDD    to 3.3V DC
   Connect GROUND to common ground 
   TCS LED to D10.....D2/PIN 2
   External LED to D8
   */    

/* Initialise with default values (int time = 2.4ms, gain = 1x) */
// Adafruit_TCS34725 tcs = Adafruit_TCS34725();

/* Initialise with int time and gain values */
//https://adafruit.github.io/Adafruit_TCS34725/html/_adafruit___t_c_s34725_8h.html
//gain 1X, 4X, 16X, 60X
//int time 2?4, 24, 50, 60, 101, 120, 154, 180, 199, 240, 300, 360, 401, 420, 480, 499, 540, 600, 614
Adafruit_TCS34725 tcs = Adafruit_TCS34725(TCS34725_INTEGRATIONTIME_480MS, TCS34725_GAIN_60X); // if changed, update message in setup()
const int INTERVAL = 614; //copying longest integration time that the sensor would use for the built in LED

const int READS = 8;
const int LED_LIGHTUP_TIME = 1;

/*
const int currentPin1 = 2; //electrode 1 via 100k restistor
const int currentPin2 = 3; //electrode 2 via 100k restistor
const int voltagePin1 = A0; //ADC 1 read
const int voltagePin2 = A1; //ADC 2 read
const int voltagePin3 = A2; //ADC 3 read current over R2

float upperBound = 1023.0;
*/
const int OUTER_ELECTRODE1 = 0;
const int OUTER_ELECTRODE2 = 1;
const int INNER_ELECTRODE1 = A0;
const int INNER_ELECTRODE2 = A1;
const int RESISTOR_READ = A2;
const int TEMP_SENSOR_PIN = 5; 

// GPIO where the DS18B20 signal pin is connected
#define ONE_WIRE_BUS TEMP_SENSOR_PIN 
#define TCS_LED_PIN 10
#define EXT_LED_PIN 8

// Setup a oneWire instance
OneWire oneWire(ONE_WIRE_BUS);

// Pass oneWire reference to DallasTemperature library
DallasTemperature sensors(&oneWire);

//for use with conductivity sensor
const int OSCILLATION_FREQUENCY = 1000; // Hz
const int SAMPLE_DELAY = 100; // ms
const int HALF_SEC_MICROS = 500000; //half a second in micros

float TEMP_COEF = 0.02; // Typical for conductivity calcs - 2%/degree
float BOARD_VOLTAGE = 3.3; // MKR1310 logic voltage
float STANDARD_REF_TEMP = 25.0; // standardised temperature for conductivity measurements
const float UPPER_BOUND = 4095.0; //12 bit resolution, if using 10 bit change to 1023.0

uint16_t Temperature = 0;
uint16_t Conductivity = 0;
uint16_t Red = 0;
uint16_t Green = 0;
uint16_t Blue = 0;


void setup(void) {
  //delay to allow interaction with board on startup before going to deep sleep
  delay(20000);

  Serial.begin(9600);

  //switch to 12 bit resolution
  analogReadResolution(12); //if using 10 bit change to 1023.0

  pinMode(OUTER_ELECTRODE1, OUTPUT);
  pinMode(OUTER_ELECTRODE2, OUTPUT);
  pinMode(INNER_ELECTRODE1, INPUT);
  pinMode(INNER_ELECTRODE2, INPUT);
  pinMode(RESISTOR_READ, INPUT);
  pinMode(TEMP_SENSOR_PIN, INPUT);
  /*
  pinMode(currentPin1, OUTPUT);
  pinMode(currentPin2, OUTPUT);
  pinMode(voltagePin3, INPUT);  
  pinMode(voltagePin2, INPUT);  
  pinMode(voltagePin1, INPUT); 
  */  
  pinMode(TCS_LED_PIN, OUTPUT);
  digitalWrite(TCS_LED_PIN, LOW);  
  pinMode(EXT_LED_PIN, OUTPUT);
  digitalWrite(EXT_LED_PIN, LOW);   

  delay(1000);
  Serial.println("Starting");

  delay(1000);
  //start up sensor


  if (tcs.begin()) {
    Serial.println("Found sensor");
  } else {
    Serial.println("No TCS34725 found ... check your connections");
    while (1);
  }
  Serial.print("READS:");
  Serial.println(READS);
  Serial.print("LED_LIGHTUP_TIME:");
  Serial.println(LED_LIGHTUP_TIME);
  
  Serial.println("TCS Integration Time: TCS34725_INTEGRATIONTIME_480MS:");


  //startup LoRa modem instance set regional band 
  if (!modem.begin(EU868)) {
    Serial.println("Failed to start module");
  }

  Serial.print("Your device EUI is: ");
  Serial.println(modem.deviceEUI());

  int connected = modem.joinOTAA(appEui, appKey);
  if (!connected) {
    Serial.println("Unable to connect");
  }
}

void loop(void) {
  USBDevice.detach(); //possibly detach in production version

  //get colour values
  readRGBValues();
  
  //get conductivity and temperature values
  processConductivity();

  //send data via LoRa
  sendLora();

  delay(1000);

  //go into sleep mode
  LowPower.deepSleep(600000);
 
}

void sendLora(){
    // Split readings (16 bits) into 2 bytes of 8
  int payloadLen = 10;
  Serial.println(payloadLen);
  
  byte payload[payloadLen];
  payload[0] = highByte(Temperature);
  payload[1] = lowByte(Temperature);
  payload[2] = highByte(Conductivity);
  payload[3] = lowByte(Conductivity);
  
  payload[4] = highByte(Red);
  payload[5] = lowByte(Red);
  payload[6] = highByte(Green);
  payload[7] = lowByte(Green);
  payload[8] = highByte(Blue);
  payload[9] = lowByte(Blue);

  modem.beginPacket();
  modem.write(payload, sizeof(payload));
  int err = modem.endPacket(true);
  if (err > 0) {
    Serial.println("Message sent correctly");
  } else {
    Serial.println("Error sending message");
  }
}

//function to get conductivity values
//to the code takes multiple readings
//the highest and lowest values are dropped to help reduce the opportunity for erroneous values to be included
//the central values are then averaged 
void processConductivity(){
  // Generate oscillating current and read voltages
  std::vector<int> readings1;
  std::vector<int> readings2;
  std::vector<int> resistorReadings;
  
  unsigned long startTime = millis();
  int sampleCount = 0;

  //loop for specified time taking multiple readings
  while (millis() - startTime < SAMPLE_DELAY) {
    digitalWrite(OUTER_ELECTRODE1, HIGH);
    digitalWrite(OUTER_ELECTRODE2, LOW);
    delayMicroseconds(500000 / OSCILLATION_FREQUENCY);
    
    readings1.push_back(analogRead(INNER_ELECTRODE1));
    readings2.push_back(analogRead(INNER_ELECTRODE2));
    resistorReadings.push_back(analogRead(RESISTOR_READ));
    sampleCount++;
    
    digitalWrite(OUTER_ELECTRODE1, LOW);
    digitalWrite(OUTER_ELECTRODE2, HIGH);
    delayMicroseconds(500000 / OSCILLATION_FREQUENCY);
    
    readings1.push_back(analogRead(INNER_ELECTRODE1));
    readings2.push_back(analogRead(INNER_ELECTRODE2));
    resistorReadings.push_back(analogRead(RESISTOR_READ));
    sampleCount++;
  }
  
  //process the arrays, dropping highest and lowest values before averaging
  float avgVoltage1 = trimAndAverageReadings(readings1, sampleCount);
  float avgVoltage2 = trimAndAverageReadings(readings2, sampleCount);
  float avgResistorVoltage = trimAndAverageReadings(resistorReadings, sampleCount);
  
  //read temperature
  sensors.requestTemperatures(); // get temperature
  float temperature = sensors.getTempCByIndex(0); // Get temperature in Celsius
  Temperature = (uint16_t)(temperature * 100.0);
  Serial.print("temperature: ");
  Serial.println(temperature,3);
  Serial.println(Temperature);

  //convert to voltages
  float voltage1 = (avgVoltage1 / UPPER_BOUND) * BOARD_VOLTAGE;
  float voltage2 = (avgVoltage2 / UPPER_BOUND) * BOARD_VOLTAGE;
  float measuredVoltage = (avgResistorVoltage / UPPER_BOUND) * BOARD_VOLTAGE;
  Conductivity = (uint16_t)(measuredVoltage * 100);
  Serial.println(Conductivity);


  // Print raw and converted values
  Serial.print("Raw1: ");
  Serial.print(avgVoltage1);
  Serial.print(" Raw2: ");
  Serial.print(avgVoltage2);
  Serial.print(" RawMeasured: ");
  Serial.print(avgResistorVoltage);
  Serial.print(" V1: ");
  Serial.print(voltage1, 3);
  Serial.print(" V2: ");
  Serial.print(voltage2, 3);
  Serial.print(" VMeasured: ");
  Serial.println(measuredVoltage, 3);

}

//drop highest and lowest n% of values to reduce noise
float trimAndAverageReadings(std::vector<int>& readings, int numReadings) {
    if (readings.empty() || numReadings < 3) {
        return 0.0f;  // return 0 if the list is empty or numReadings is too small
    }

    //sort the vector
    std::sort(readings.begin(), readings.end());

    // calc number of elements to trim
    int trimCount = std::round(numReadings * 0.2);  // 20% from top and bottom
    
    // don't trim more than half the values
    trimCount = std::min(trimCount, ((int)readings.size() / 2) - 1);

    // sum up
    float sum = 0;
    for (int i = trimCount; i < readings.size() - trimCount; ++i) {
        sum += readings[i];
    }

    // retrun average
    int remainingElements = readings.size() - (2 * trimCount); //2x - 1 at each end
    return sum / remainingElements;
}



//function to get RGB values
//multiple reads are taken to improve accuracy
//high and low values are dropped and the core values averaged
void readRGBValues(){
  uint16_t r, g, b, c; //, colorTemp, lux;
  std::vector<int> rVals;
  std::vector<int> gVals;
  std::vector<int> bVals;
  std::vector<int> cVals;

  //switch on external LED
  digitalWrite(EXT_LED_PIN, HIGH);  

  delay(LED_LIGHTUP_TIME);
  //waitForMillis(INTERVAL);

  for (int i=0; i<READS; i++){
    tcs.getRawData(&r, &g, &b, &c);
    rVals.push_back(r);
    gVals.push_back(g);
    bVals.push_back(b);
    cVals.push_back(c);
    delay(5);
    //waitForMillis(5);
  }
  
  //switch off external LED
  digitalWrite(EXT_LED_PIN, LOW); 

  r = (uint16_t)trimAndAverageReadings(rVals, READS);
  g = (uint16_t)trimAndAverageReadings(gVals, READS);
  b = (uint16_t)trimAndAverageReadings(bVals, READS);
  c = (uint16_t)trimAndAverageReadings(cVals, READS);
  
  Red = r;
  Green = g;
  Blue = b;
  Serial.println(Red);
  Serial.println(Green);
  Serial.println(Blue);
  // colorTemp = tcs.calculateColorTemperature(r, g, b);
  //colorTemp = tcs.calculateColorTemperature_dn40(r, g, b, c);
  //lux = tcs.calculateLux(r, g, b);

  //Serial.print("Color Temp: "); Serial.print(colorTemp, DEC); Serial.print(" K - ");
  //Serial.print("Lux: "); Serial.print(lux, DEC); Serial.print(" - ");
  Serial.print("R: "); Serial.print(r, DEC); Serial.print(" ");
  Serial.print("G: "); Serial.print(g, DEC); Serial.print(" ");
  Serial.print("B: "); Serial.print(b, DEC); Serial.print(" ");
  Serial.print("C: "); Serial.print(c, DEC); Serial.print(" ");
  Serial.println(" ");
}

void waitForMillis(int period){
  unsigned long currentMillis = millis();
  unsigned long waitPeriod = currentMillis + period;
  while (waitPeriod > currentMillis) {
    currentMillis = millis();
    yield();
  }
}

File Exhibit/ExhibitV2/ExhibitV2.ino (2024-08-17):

/////////////////////////////////////////////////////////////////////////////////////
/// This sketch is designed for the CE Exhibition
/// It is intended for use with LED matrix and TCS34725 to take RGB readings
/// The LED matrix is used to display user instructions and readings
/// Code is based on the example in matrixtest in Adafruit_NeoMatrix library with
/// changes to display more text and interupts to handle user interaction. 
/// Example from cyaninfinite.com/scrolling-text-with-flexible-32x8-rgb-led-matrix also used
/// Coded by mfoster
/////////////////////////////////////////////////////////////////////////////////////


/* Example code for the Adafruit TCS34725 breakout library */

/* For Nano set up
   Connect SCL    to analog 5
   Connect SDA    to analog 4
   Connect VDD    to 3.3V DC
   Connect GROUND to common ground 
   LED to D2/PIN 2... now using 13
   */

#include <Adafruit_GFX.h>
#include <Adafruit_NeoMatrix.h>
#include <Adafruit_NeoPixel.h>
#include <Wire.h>
#include "Adafruit_TCS34725.h"

#ifndef PSTR
 #define PSTR // Make Arduino Due happy
#endif

#define PIN 6

// MATRIX DECLARATION:
// Parameter 1 = width of NeoPixel matrix
// Parameter 2 = height of matrix
// Parameter 3 = pin number (most are valid)
// Parameter 4 = matrix layout flags, add together as needed:
//   NEO_MATRIX_TOP, NEO_MATRIX_BOTTOM, NEO_MATRIX_LEFT, NEO_MATRIX_RIGHT:
//     Position of the FIRST LED in the matrix; pick two, e.g.
//     NEO_MATRIX_TOP + NEO_MATRIX_LEFT for the top-left corner.
//   NEO_MATRIX_ROWS, NEO_MATRIX_COLUMNS: LEDs are arranged in horizontal
//     rows or in vertical columns, respectively; pick one or the other.
//   NEO_MATRIX_PROGRESSIVE, NEO_MATRIX_ZIGZAG: all rows/columns proceed
//     in the same order, or alternate lines reverse direction; pick one.
//   See example below for these values in action.
// Parameter 5 = pixel type flags, add together as needed:
//   NEO_KHZ800  800 KHz bitstream (most NeoPixel products w/WS2812 LEDs)
//   NEO_KHZ400  400 KHz (classic 'v1' (not v2) FLORA pixels, WS2811 drivers)
//   NEO_GRB     Pixels are wired for GRB bitstream (most NeoPixel products)
//   NEO_GRBW    Pixels are wired for GRBW bitstream (RGB+W NeoPixel products)
//   NEO_RGB     Pixels are wired for RGB bitstream (v1 FLORA pixels, not v2)


// Example for NeoPixel Shield.  In this application we'd like to use it
// as a 5x8 tall matrix, with the USB port positioned at the top of the
// Arduino.  When held that way, the first pixel is at the top right, and
// lines are arranged in columns, progressive order.  The shield uses
// 800 KHz (v2) pixels that expect GRB color data.
Adafruit_NeoMatrix matrix = Adafruit_NeoMatrix(32, 8, PIN,
  NEO_MATRIX_BOTTOM    + NEO_MATRIX_RIGHT +
  NEO_MATRIX_COLUMNS + NEO_MATRIX_ZIGZAG,
  NEO_GRB            + NEO_KHZ800);
  
const uint16_t colors[] = {
  matrix.Color(255, 0, 0), matrix.Color(0, 255, 0), matrix.Color(0, 0, 255) };


#include <avr/sleep.h>
const int awakePeriod = 30000;
const int wakeUpPin = 3;
const int actionPin = 2;

volatile bool sleepFlag = false;
volatile bool actionFlag = false;
volatile bool promptFlag = true;

unsigned long lastInteraction = millis();

/* Initialise TCS with specific int time and gain values */
Adafruit_TCS34725 tcs = Adafruit_TCS34725(TCS34725_INTEGRATIONTIME_240MS, TCS34725_GAIN_1X);

#define LED_PIN 13
//#define EXT_LED_PIN 4

//global colour values
 uint16_t r, g, b, c, colorTemp, lux;

void setup() {
  
  Serial.begin(9600);
  pinMode(wakeUpPin, INPUT_PULLUP);
  
  pinMode(actionPin, INPUT_PULLUP);
  
  attachInterrupt(digitalPinToInterrupt(wakeUpPin), wakeUp, FALLING);
  
  attachInterrupt(digitalPinToInterrupt(actionPin), doAction, FALLING);

  Serial.begin(9600);
  matrix.begin();
  matrix.setTextWrap(false);
  matrix.setBrightness(30);
  matrix.setTextColor(colors[0]);

  const __FlashStringHelper* text = F("Hi there!");
  displayText(text,2,30);
  

  
  pinMode(LED_PIN, OUTPUT);
  digitalWrite(LED_PIN, LOW);  

  if (tcs.begin()) {
    Serial.println("Found sensor");
  } else {
    Serial.println("No TCS34725 found ... check your connections");
    while (1);
  }

  actionFlag = false;

}

//on each loop check if it is time to sleep and if the user has pressed a button then react
void loop() {
  checkTime();
  if (sleepFlag) {
    Serial.println("Going to sleep...");
    delay(1000);
    sleep();
  } 
  
  digitalWrite(LED_PIN, LOW);

  delay(10); //slow things down
  Serial.println("Awake!");

  if (promptFlag){
    Serial.println("Prompting user");
    const __FlashStringHelper* text = F("Insert a sample and press 'Read' to examine it");
    displayText(text, 1, 40);

    lastInteraction = millis();
    promptFlag = false;
  }

  if (actionFlag){
    Serial.println("It's action time!");
    readSample();
    actionFlag = false;
  }

}
int x    = matrix.width();
int pass = 0;

void displayText(const __FlashStringHelper* text, int colour){
  displayText(text, colour, 50);
}
// function to simplify the call to display text on the pixel matrix
// textSpeed will speed up (decrease the delay) or slow down (increase the delay) the text (pixel) progression across the matrix
//    the overloaded function above uses 50 as the default value
void displayText(const __FlashStringHelper* text, int colour, int textSpeed) {
  
  int length = static_cast<int>(strlen_P((const char*)text));
  int i = 0;

  for (i=0; i < (length * 6)+33; i++){
    matrix.fillScreen(0);
    matrix.setCursor(x, 0);
    matrix.setTextColor(colors[colour]);

    matrix.print(text);
    if(--x < -1 * (length * 6)) {
      x = matrix.width();
      //if(++pass >= 3) pass = 0;
      //matrix.setTextColor(colors[pass]);
    }
    matrix.show();
    delay(textSpeed);
  }
  matrix.fillScreen(0);
  matrix.show();
}

   // get user to interact
    //sleepFlag = true;

//read from TCS sensor
void readSample(){
  
  tcs.getRawData(&r, &g, &b, &c);
  // colorTemp = tcs.calculateColorTemperature(r, g, b);
  colorTemp = tcs.calculateColorTemperature_dn40(r, g, b, c);
  lux = tcs.calculateLux(r, g, b);

  long total = (long)(r + g + b);

  int rPix = (r * 32) / total;
  int gPix = (g * 32) / total;
  int bPix = (b * 32) / total;


  Serial.print("Color Temp: "); Serial.print(colorTemp, DEC); Serial.print(" K - ");
  Serial.print("Lux: "); Serial.print(lux, DEC); Serial.print(" - ");
  Serial.print("R: "); Serial.print(r, DEC); Serial.print(" ");
  Serial.print("G: "); Serial.print(g, DEC); Serial.print(" ");
  Serial.print("B: "); Serial.print(b, DEC); Serial.print(" ");
  Serial.print("C: "); Serial.print(c, DEC); Serial.print(" ");
  Serial.println(" ");
  Serial.print("Ratio Pixels: "); Serial.print(rPix); Serial.print(" "); Serial.print(gPix); Serial.print(" "); Serial.print(bPix); Serial.println(" ");
  
  displayColourRatios();

  digitalWrite(LED_PIN, LOW);
  //digitalWrite(EXT_LED_PIN, LOW);



}
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
